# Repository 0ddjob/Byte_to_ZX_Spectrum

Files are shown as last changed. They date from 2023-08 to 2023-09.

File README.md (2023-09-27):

# Byte_to_ZX_Spectrum
Converter board for the Belarusian ZX Spectrum clone called the Байт (Byte). <br>
 
This machine has an, ahem, excessive 96-pin connector called an СНП59-96 (SNP59).  This connector has three rows of 32 pins each and is *almost* the same as a DIN41612 connector ... except for the Soviet-era 2.5mm pin pitch (compared to Western 2.54mm).  <br>

So a DIN41612 connector will not work.  That's the first issue.<br>

The second issue is, of course, it's not a Spectrum edge connector so peripherals won't connect anyway.

The problem

Special notes "Connecting DivIDE to BYTE":
- Pin A25 from divIDE we connect to byte on which we send out a low romcs signal such as the pin A30:
- Cut pin 4 or 4/5 of the DD67 (555ИД7) chip from ground and solder a resistor (180Ω to 10kΩ)
- Use a cable to lead pin 4 or 4/5 to a free pin of the edge connector, e.g. A30
- ROMCS signal (A25) from DivIDE connect to pin A30

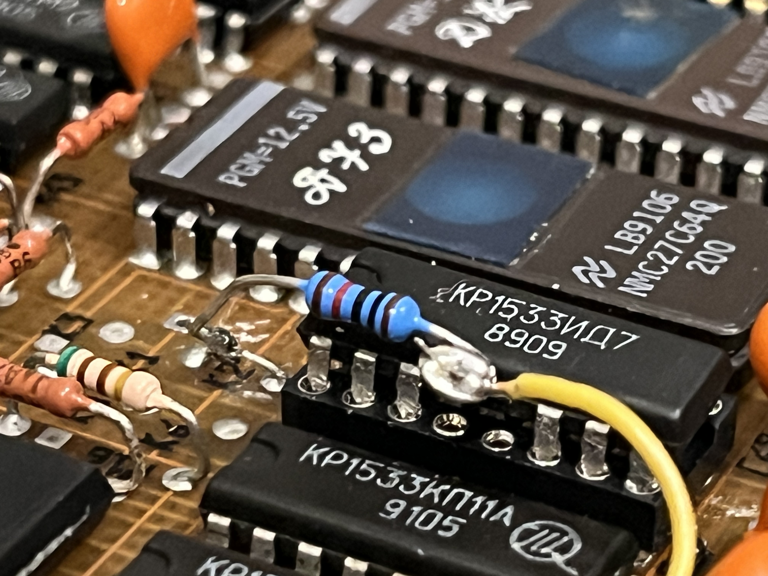
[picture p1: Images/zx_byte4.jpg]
ROMCS signal


Current status (28-Sept-2023):<br>
- Connectors and test boards have arrived<br>
- Not working with DivMMC - investigating<br>

Test board

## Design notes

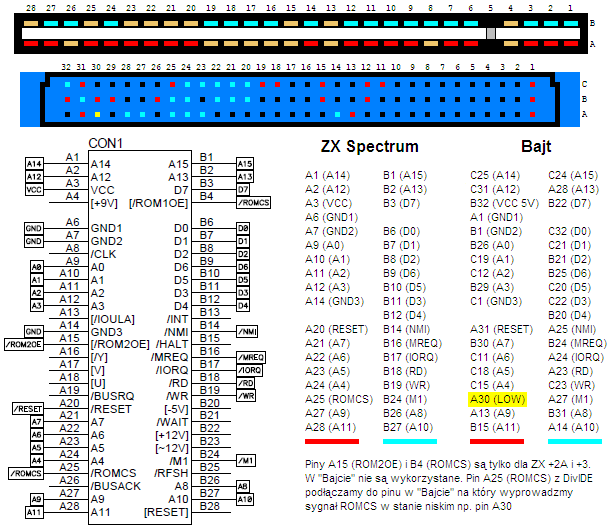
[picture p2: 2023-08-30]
Images/Interface_conversion.png

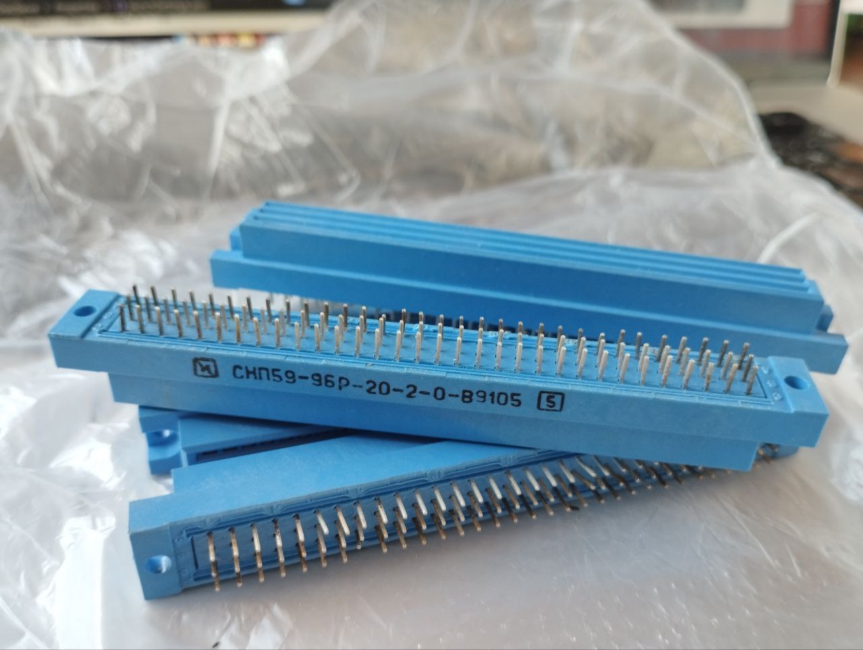
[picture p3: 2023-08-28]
Images/SNP59_96 connectors.jpeg

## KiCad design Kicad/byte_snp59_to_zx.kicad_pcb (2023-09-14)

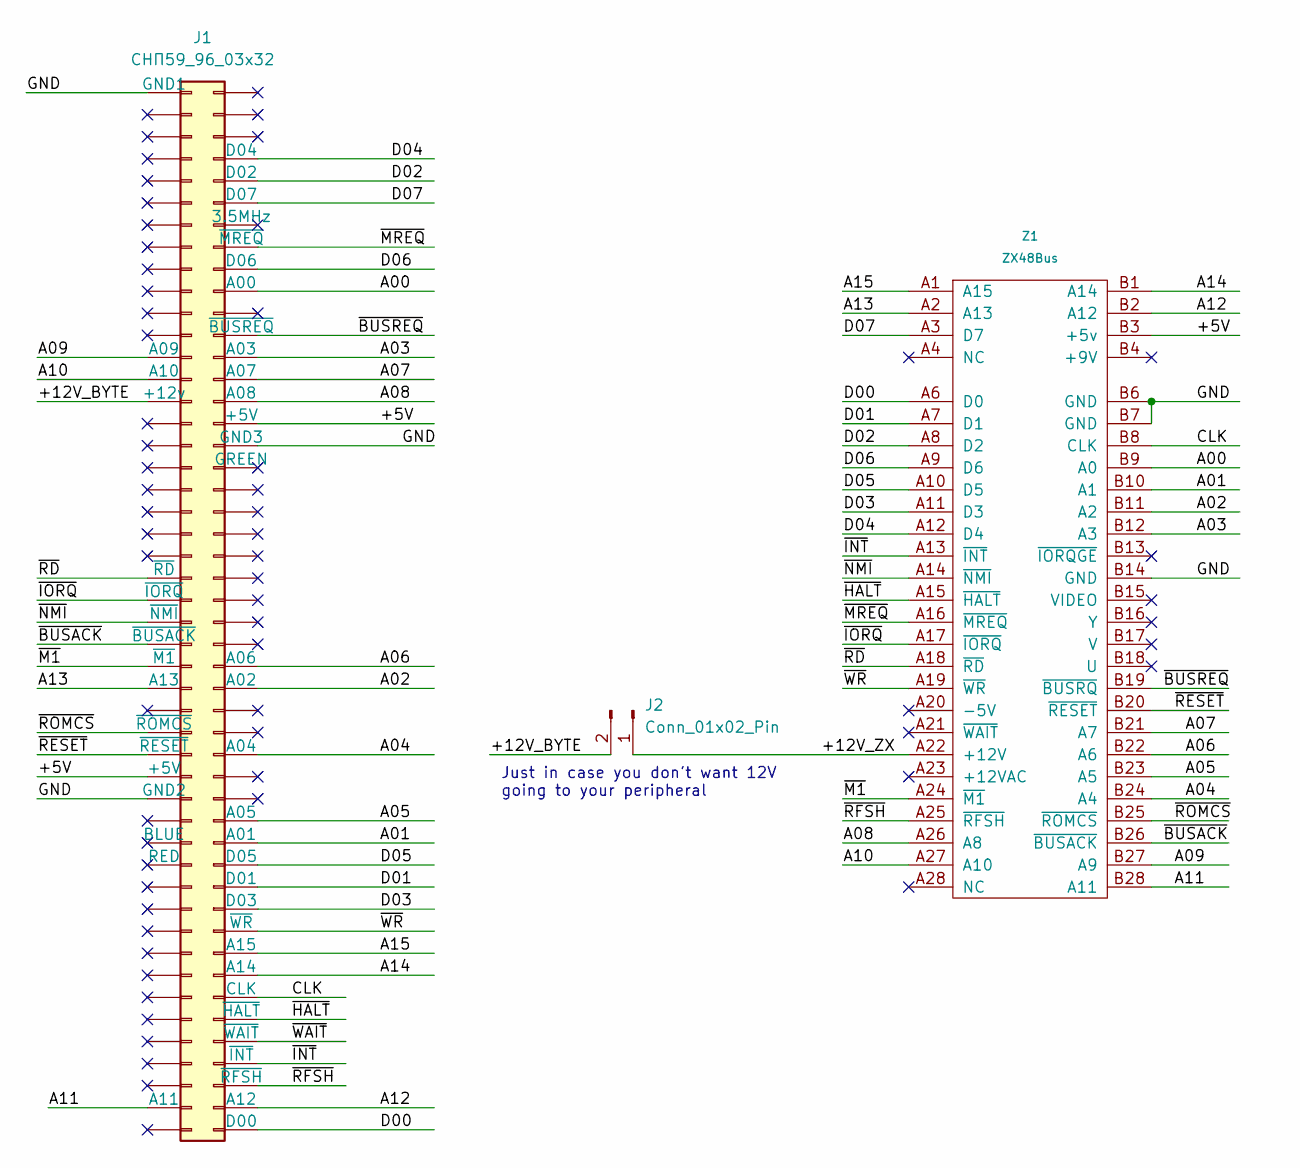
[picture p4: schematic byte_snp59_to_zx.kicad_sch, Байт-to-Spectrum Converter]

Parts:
J1: СНП59_96_03x32; SNP59_96_Female
J2: Conn_01x02_Pin; PinHeader_1x02_P2.54mm_Vertical
Z1: ZX48Bus; ZX_Bus_Edge_Connector

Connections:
/+5V: J1.a32 (+5V), J1.b32 (+5V), Z1.B3 (+5v)
/+12V_BYTE: J1.a15 (+12v), J2.2
/+12V_ZX: J2.1, Z1.A22 (+12V)
/A00: J1.b26 (A00), Z1.B9 (A0)
/A01: J1.c19 (A01), Z1.B10 (A1)
/A02: J1.c12 (A02), Z1.B11 (A2)
/A03: J1.b29 (A03), Z1.B12 (A3)
/A04: J1.c15 (A04), Z1.B24 (A4)
/A05: J1.c18 (A05), Z1.B23 (A5)
/A06: J1.c11 (A06), Z1.B22 (A6)
/A07: J1.b30 (A07), Z1.B21 (A7)
/A08: J1.b31 (A08), Z1.A26 (A8)
/A09: J1.a13 (A09), Z1.B27 (A9)
/A10: J1.a14 (A10), Z1.A27 (A10)
/A11: J1.b15 (A11), Z1.B28 (A11)
/A12: J1.c31 (A12), Z1.B2 (A12)
/A13: J1.a28 (A13), Z1.A2 (A13)
/A14: J1.c25 (A14), Z1.B1 (A14)
/A15: J1.c24 (A15), Z1.A1 (A15)
/CLK: J1.c26 (CLK), Z1.B8 (CLK)
/D00: J1.c32 (D00), Z1.A6 (D0)
/D01: J1.c21 (D01), Z1.A7 (D1)
/D02: J1.b21 (D02), Z1.A8 (D2)
/D03: J1.c22 (D03), Z1.A11 (D3)
/D04: J1.b20 (D04), Z1.A12 (D4)
/D05: J1.c20 (D05), Z1.A10 (D5)
/D06: J1.b25 (D06), Z1.A9 (D6)
/D07: J1.b22 (D07), Z1.A3 (D7)
/GND: J1.a1 (GND1), J1.b1 (GND2), J1.c1 (GND3), Z1.B6 (GND), Z1.B7 (GND), Z1.B14 (GND)
/~BUSACK: J1.a26 (~BUSACK), Z1.B26 (~BUSACK)
/~BUSREQ: J1.b28 (~BUSREQ), Z1.B19 (~BUSRQ)
/~HALT: J1.c27 (~HALT), Z1.A15 (~HALT)
/~INT: J1.c29 (~INT), Z1.A13 (~INT)
/~IORQ: J1.a24 (~IORQ), Z1.A17 (~IORQ)
/~M1: J1.a27 (~M1), Z1.A24 (~M1)
/~MREQ: J1.b24 (~MREQ), Z1.A16 (~MREQ)
/~NMI: J1.a25 (~NMI), Z1.A14 (~NMI)
/~RD: J1.a23 (~RD), Z1.A18 (~RD)
/~RESET: J1.a31 (~RESET), Z1.B20 (~RESET)
/~RFSH: J1.c30 (~RFSH), Z1.A25 (~RFSH)
/~ROMCS: J1.a30 (~ROMCS), Z1.B25 (~ROMCS)
/~WAIT: J1.c28 (~WAIT)
/~WR: J1.c23 (~WR), Z1.A19 (~WR)

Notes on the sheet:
Just in case you don't want 12V going to your peripheral

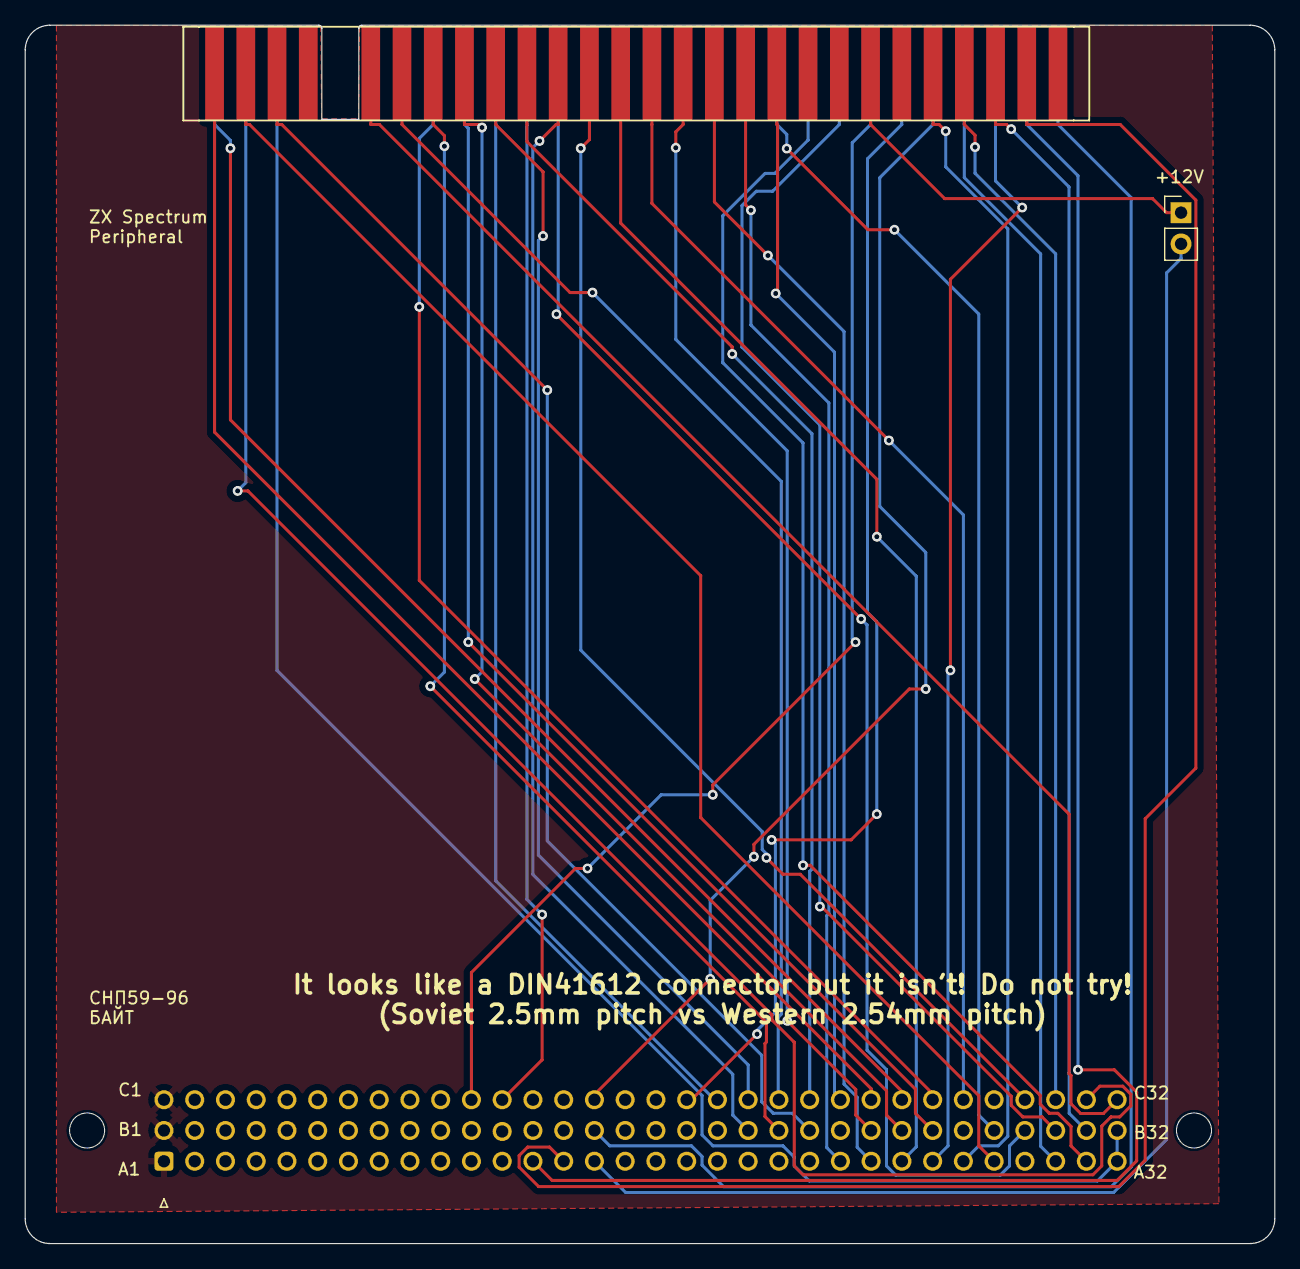
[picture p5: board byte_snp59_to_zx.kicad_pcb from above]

Board: 2 copper layers, 101.6 x 99.1 mm, 3 parts (0 on the bottom side), 42 nets.

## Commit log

2023-08-28 Connector image
2023-08-29 Initial test design
    [byte_snp59_to_zx.kicad_pcb, byte_snp59_to_zx.kicad_sch]
2023-08-29 Image showing the problem to be solved
    The Bealrusian BYTE computer has an "excessive" 96-pin system bus expansion connector ... with Soviet-era 2.5mm pin pitch.
2023-09-14 Updated PCB text & generated prototype Gerber files
    [byte_snp59_to_zx.kicad_pcb]
